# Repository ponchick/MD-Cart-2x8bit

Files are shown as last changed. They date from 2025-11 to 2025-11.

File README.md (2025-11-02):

# MD-Cart-2x8bit

A KiCad project for a Sega Mega Drive/Genesis cartridge PCB. Designed to use two standard 8-bit 32-pin ROMs to form a 16-bit ROM bus.

## Hardware Requirements

Most parallel ROMs in DIP-32 packages with 8-bit memory organization should work. For EEPROM/Flash chips, solder jumper pins 1-2; for EPROM chips, solder pins 2-3.

### Compatible ROM Chips

The following DIP-32 8-bit *ROM chips have been tested and confirmed working with this design:

| Chip Model | Capacity | Organization | Jumpers |
|---|---|---|---|
| ST M27C1001 | 128 KB | 1 Mbit × 8 | 2-3 |
| Winbond W27C020 | 256 KB | 2 Mbit × 8 | 1-2 |
| AMIC A29040B | 512 KB | 4 Mbit × 8 | 1-2 |
| SST SST39SF040 | 512 KB | 4 Mbit × 8 | 1-2 |
| ST M27C801 | 1 MB | 8 Mbit × 8 | 2-3 |

## Scripts

### split_msb_lsb.py

Splits a 16-bit binary file into upper and lower byte files for programming into two separate 8-bit ROMs. Supports big-endian (default for Motorola 68000) and little-endian byte order.

**Requirements:** Python 3.6 or higher. Optional: `libarchive-c` for archive format support.

#### Usage

```bash
python3 scripts/split_msb_lsb.py <filename> [options]
```

#### Options

- `filename` (required)
  - Input binary file or archive (.7z, .zip, .rar) to split
  - If an archive is provided, the first file found will be processed

- `--little-endian`
  - Use little-endian byte order instead of big-endian
  - Default: big-endian (Motorola 68000 standard)

- `-f, --force`
  - Overwrite existing output files without prompting
  - Default: prompt for confirmation if output files exist

- `-o, --output PREFIX`
  - Specify output filename prefix
  - Default: uses input filename as base
  - If `PREFIX` is an existing directory, files are saved there with original filename
  - Output files are named: `<prefix>.lower.bin` and `<prefix>.upper.bin`

- `--odd-byte {skip,lower,upper,error}`
  - Action to take when input file has odd number of bytes:
    - `error` (default): Print error and exit
    - `skip`: Skip the odd byte with a warning
    - `lower`: Add the odd byte to the lower byte file
    - `upper`: Add the odd byte to the upper byte file

#### Examples

```bash
# Basic usage (big-endian)
python3 scripts/split_msb_lsb.py rom.bin

# Little-endian byte order
python3 scripts/split_msb_lsb.py rom.bin --little-endian

# Specify output prefix
python3 scripts/split_msb_lsb.py rom.bin -o output/myrom

# Process archive and force overwrite
python3 scripts/split_msb_lsb.py game.zip -f

# Handle odd byte by adding to lower file
python3 scripts/split_msb_lsb.py rom.bin --odd-byte lower
```

#### Output

The script generates two files:

- `<prefix>.lower.bin` - Contains the lower (LSB) bytes for the first ROM
- `<prefix>.upper.bin` - Contains the upper (MSB) bytes for the second ROM

#### Archive Support

Archive format support requires `libarchive-c`:

```bash
pip install libarchive-c
```

Supported archive formats: `.7z`, `.zip`, `.rar`

## License

- Hardware: CERN Open Hardware Licence Version 2 - Permissive (CERN-OHL-P)
- Software: MIT License

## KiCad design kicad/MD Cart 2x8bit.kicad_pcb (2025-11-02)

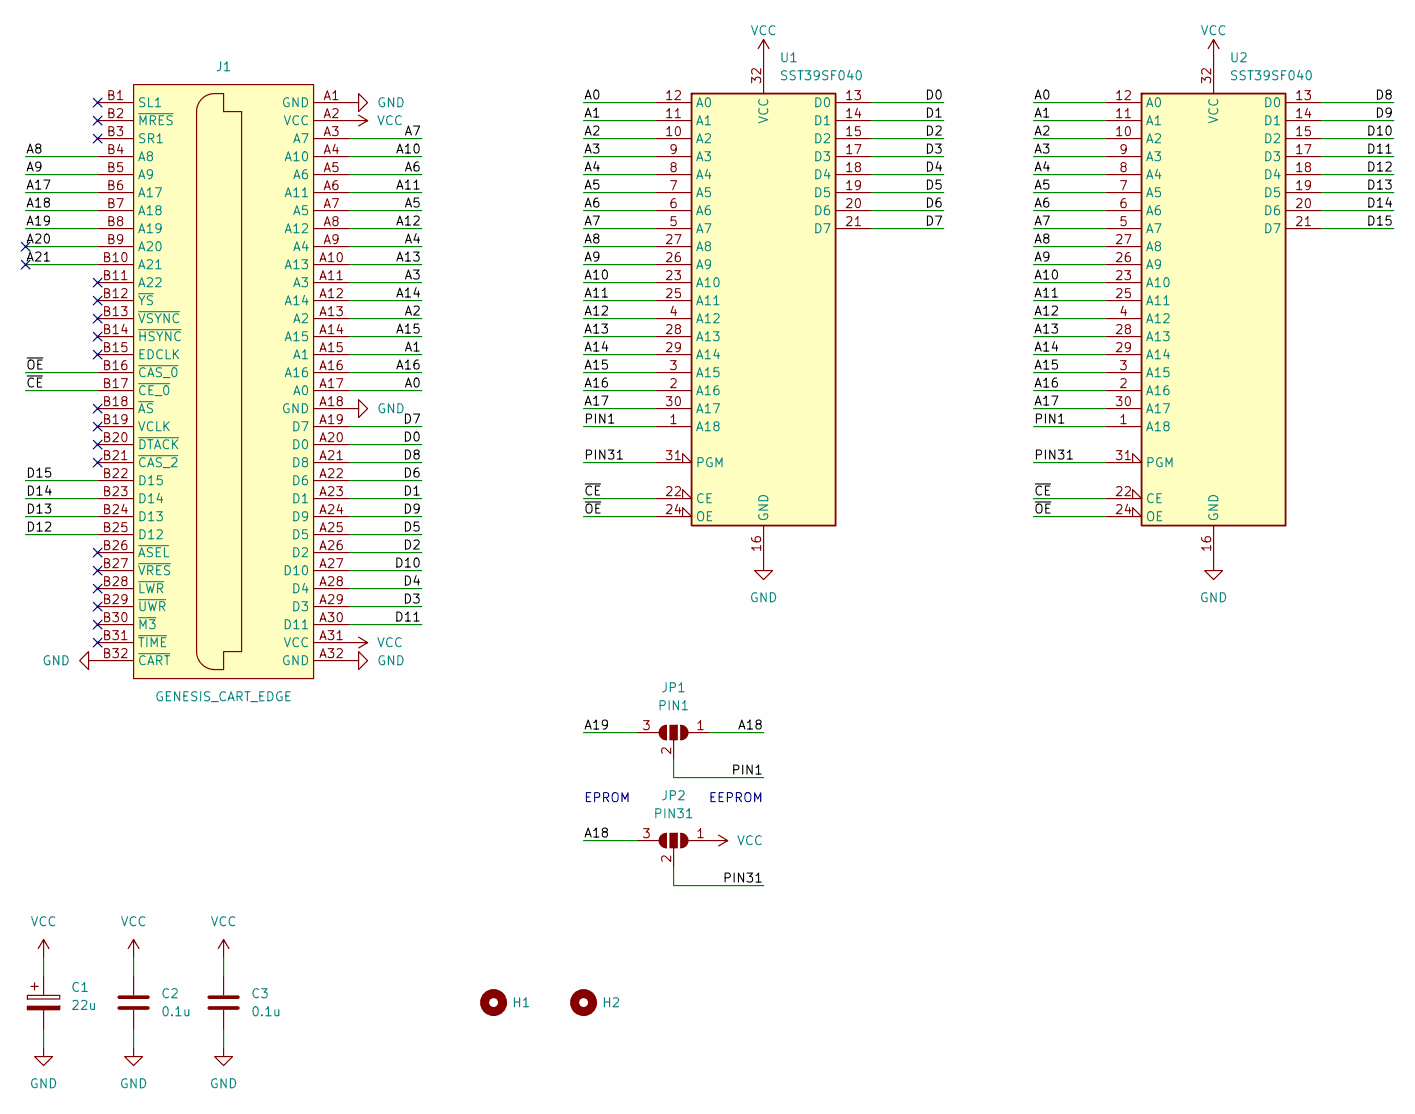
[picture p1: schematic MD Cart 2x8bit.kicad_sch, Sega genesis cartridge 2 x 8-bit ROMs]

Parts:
C1: 22u; CP_Radial_D5.0mm_P2.50mm
C2, C3: 0.1u; C_Disc_D4.3mm_W1.9mm_P5.00mm
H1, H2: HOLE_6.2
J1: GENESIS_CART_EDGE
JP1: PIN1; SolderJumper-3
JP2: PIN31; SolderJumper-3
U1, U2: SST39SF040; DIP-32_W15.24mm_Socket

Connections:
/A0: J1.A17 (A0), U1.12 (A0), U2.12 (A0)
/A1: J1.A15 (A1), U1.11 (A1), U2.11 (A1)
/A2: J1.A13 (A2), U1.10 (A2), U2.10 (A2)
/A3: J1.A11 (A3), U1.9 (A3), U2.9 (A3)
/A4: J1.A9 (A4), U1.8 (A4), U2.8 (A4)
/A5: J1.A7 (A5), U1.7 (A5), U2.7 (A5)
/A6: J1.A5 (A6), U1.6 (A6), U2.6 (A6)
/A7: J1.A3 (A7), U1.5 (A7), U2.5 (A7)
/A8: J1.B4 (A8), U1.27 (A8), U2.27 (A8)
/A9: J1.B5 (A9), U1.26 (A9), U2.26 (A9)
/A10: J1.A4 (A10), U1.23 (A10), U2.23 (A10)
/A11: J1.A6 (A11), U1.25 (A11), U2.25 (A11)
/A12: J1.A8 (A12), U1.4 (A12), U2.4 (A12)
/A13: J1.A10 (A13), U1.28 (A13), U2.28 (A13)
/A14: J1.A12 (A14), U1.29 (A14), U2.29 (A14)
/A15: J1.A14 (A15), U1.3 (A15), U2.3 (A15)
/A16: J1.A16, U1.2 (A16), U2.2 (A16)
/A17: J1.B6 (A17), U1.30 (A17), U2.30 (A17)
/A18: J1.B7 (A18), JP1.1 (A), JP2.3 (B)
/A19: J1.B8 (A19), JP1.3 (B)
/A20: J1.B9 (A20)
/A21: J1.B10 (A21)
/D0: J1.A20 (D0), U1.13 (D0)
/D1: J1.A23 (D1), U1.14 (D1)
/D2: J1.A26 (D2), U1.15 (D2)
/D3: J1.A29 (D3), U1.17 (D3)
/D4: J1.A28 (D4), U1.18 (D4)
/D5: J1.A25 (D5), U1.19 (D5)
/D6: J1.A22 (D6), U1.20 (D6)
/D7: J1.A19 (D7), U1.21 (D7)
/D8: J1.A21 (D8), U2.13 (D0)
/D9: J1.A24 (D9), U2.14 (D1)
/D10: J1.A27 (D10), U2.15 (D2)
/D11: J1.A30 (D11), U2.17 (D3)
/D12: J1.B25 (D12), U2.18 (D4)
/D13: J1.B24 (D13), U2.19 (D5)
/D14: J1.B23 (D14), U2.20 (D6)
/D15: J1.B22 (D15), U2.21 (D7)
/PIN1: JP1.2 (C), U1.1 (A18), U2.1 (A18)
/PIN31: JP2.2 (C), U1.31 (PGM), U2.31 (PGM)
/~CE: J1.B17 (~CE_0), U1.22 (CE), U2.22 (CE)
/~OE: J1.B16 (~CAS_0), U1.24 (OE), U2.24 (OE)
GND: C1.2, C2.1, C3.2, J1.A1 (GND), J1.A18 (GND), J1.A32 (GND), J1.B32 (~CART), U1.16 (GND), U2.16 (GND)
VCC: C1.1, C2.2, C3.1, J1.A2 (VCC), J1.A31 (VCC), JP2.1 (A), U1.32 (VCC), U2.32 (VCC)

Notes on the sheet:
EEPROM
EPROM

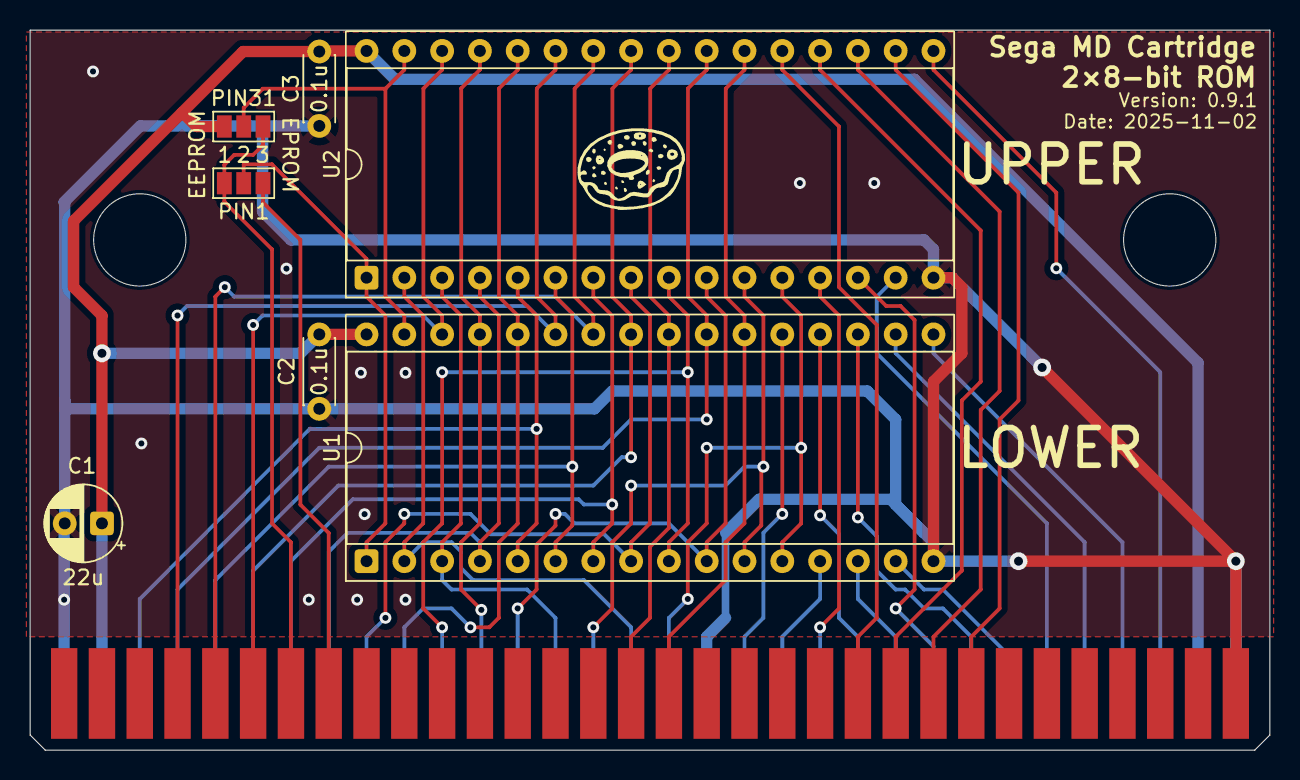
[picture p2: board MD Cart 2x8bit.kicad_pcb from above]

Board: 2 copper layers, 83.3 x 48.4 mm, 11 parts (0 on the bottom side), 42 nets.

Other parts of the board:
LOGO#: LOGO; ponchick
